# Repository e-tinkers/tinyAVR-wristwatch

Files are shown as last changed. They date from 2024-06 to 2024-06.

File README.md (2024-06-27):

## tinyAVR Wrist Watch

This is a derivated design from my entry for [Hackaday 2024 Business Card Challenge Contest](https://hackaday.io/project/196294-business-card-clock-attiny3227-dev-board). 

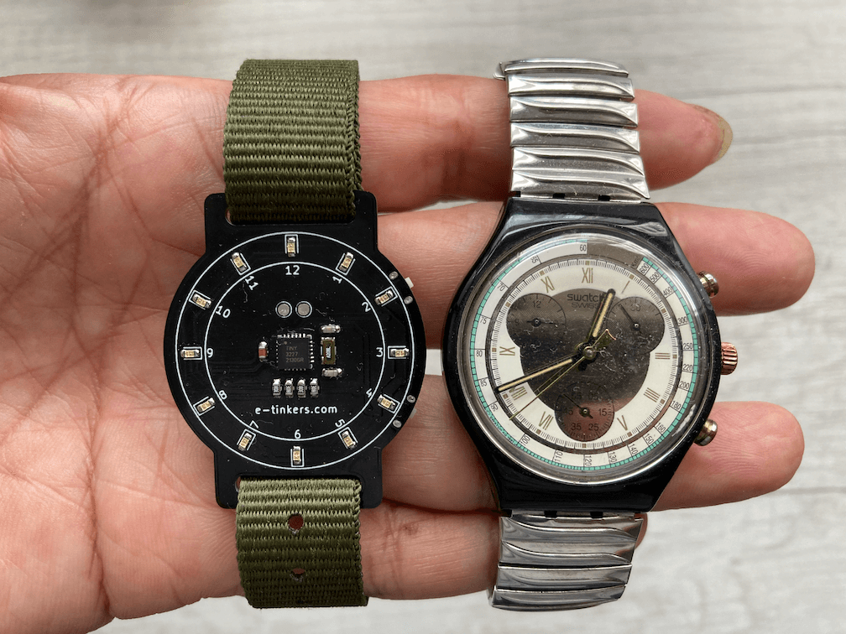
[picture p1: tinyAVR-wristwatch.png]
tinyAVR-wristwatch-with-belt


It shares the same [firmware](https://github.com/e-tinkers/tinyAVR_business_card_firmware) used in the [business card project](https://github.com/e-tinkers/tinyAVR-Business-Card), it has the same BOM with the exception of the two buttons used and without the two 12-pin break-out connector. I found a 16mm-wide wrist belt from Aliexpress and bought a few of them with different colors.

The wrist watch is powered by a CR2016 coin cell battery (96mAh) and has a sleep power consumption of less than 2uA, the battery life would be more than 3 years based on viewing the time 24 times/day.

Thanks [PCBWay](https://www.pcbway.com) for sponsoring the PCB fabrication.

You can ordering your PCB from [PCBWay](https://www.pcbway.com/project/shareproject/W515726AS2D5_gerber_22fd22c4.html)

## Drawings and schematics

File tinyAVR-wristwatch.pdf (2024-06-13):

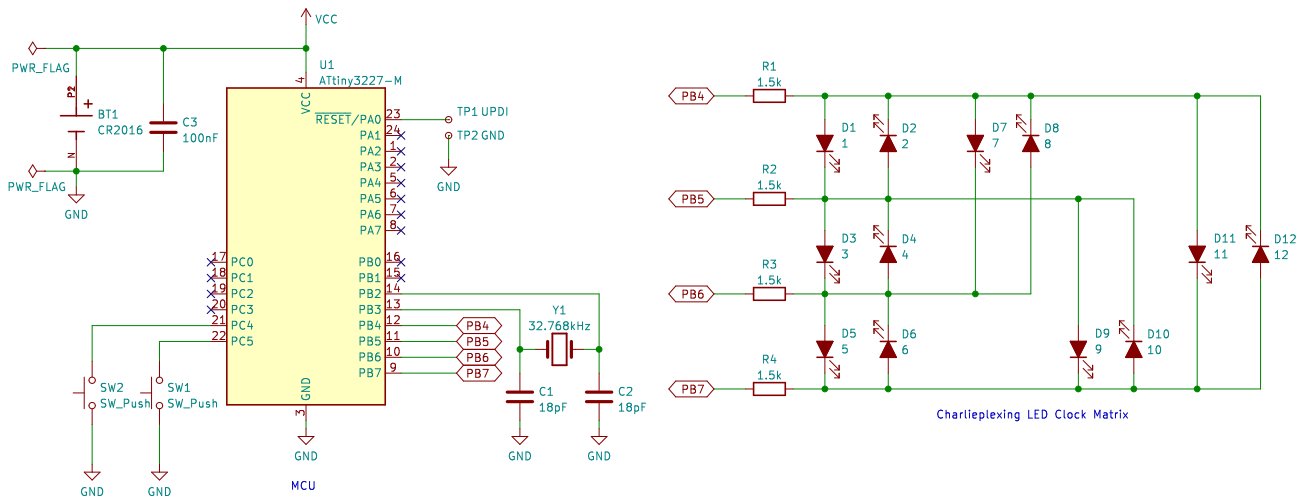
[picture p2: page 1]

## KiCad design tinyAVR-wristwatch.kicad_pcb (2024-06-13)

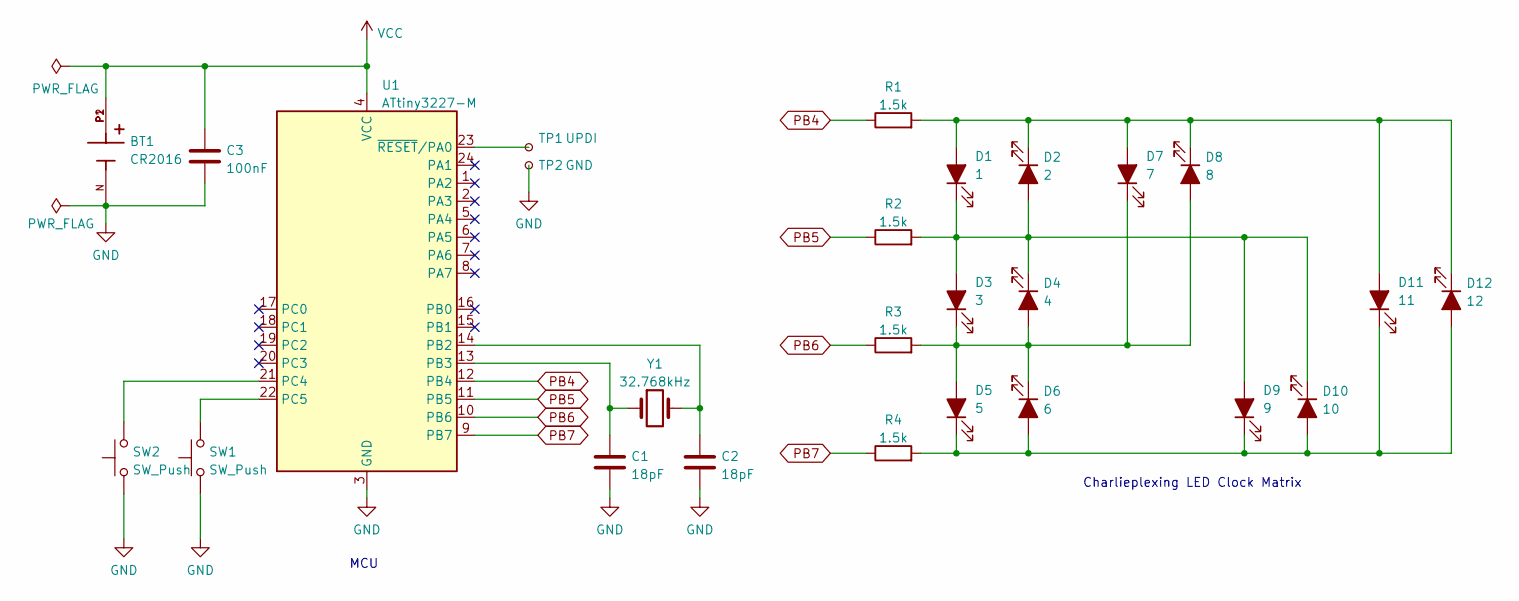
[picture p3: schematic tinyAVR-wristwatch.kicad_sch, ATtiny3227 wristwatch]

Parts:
BT1: CR2016; BatteryHolder_CR2016_SMD
C1, C2: 18pF; C_0603_1608Metric
C3: 100nF; C_0603_1608Metric
D1: 1; LED_0603_1608Metric
D2: 2; LED_0603_1608Metric
D3: 3; LED_0603_1608Metric
D4: 4; LED_0603_1608Metric
D5: 5; LED_0603_1608Metric
D6: 6; LED_0603_1608Metric
D7: 7; LED_0603_1608Metric
D8: 8; LED_0603_1608Metric
D9: 9; LED_0603_1608Metric
D10: 10; LED_0603_1608Metric
D11: 11; LED_0603_1608Metric
D12: 12; LED_0603_1608Metric
R1, R2, R3, R4: 1.5k; R_0603_1608Metric
SW1, SW2: SW_Push; KEY-SMD_TS3819ZJ
TP1: UPDI; TestPoint_Pad_D1.5mm
TP2: GND; TestPoint_Pad_D1.5mm
U1: ATtiny3227-M; QFN-24-1EP_4x4mm_P0.5mm_EP2.6x2.6mm
Y1: 32.768kHz; Crystal_SMD_3215-2Pin_3.2x1.5mm

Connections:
GND: BT1.N, C1.2, C2.2, C3.2, SW1.1, SW2.1, TP2.1, U1.3 (GND), U1.25 (GND)
unnamed: C1.1, U1.13 (PB3), Y1.1
unnamed: C2.1, U1.14 (PB2), Y1.2
unnamed: D1.1 (K), D2.2 (A), D3.2 (A), D4.1 (K), D9.2 (A), D10.1 (K), R2.2
unnamed: D1.2 (A), D2.1 (K), D7.2 (A), D8.1 (K), D11.2 (A), D12.1 (K), R1.2
unnamed: D3.1 (K), D4.2 (A), D5.2 (A), D6.1 (K), D7.1 (K), D8.2 (A), R3.2
unnamed: D5.1 (K), D6.2 (A), D9.1 (K), D10.2 (A), D11.1 (K), D12.2 (A), R4.2
unnamed: SW1.2, U1.22 (PC5)
unnamed: SW2.2, U1.21 (PC4)
unnamed: TP1.1, U1.23 (~RESET/PA0)
PB4: R1.1, U1.12 (PB4)
PB5: R2.1, U1.11 (PB5)
PB6: R3.1, U1.10 (PB6)
PB7: R4.1, U1.9 (PB7)
VCC: BT1.P1, BT1.P2, C3.1, U1.4 (VCC)

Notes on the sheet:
MCU
Charlieplexing LED Clock Matrix

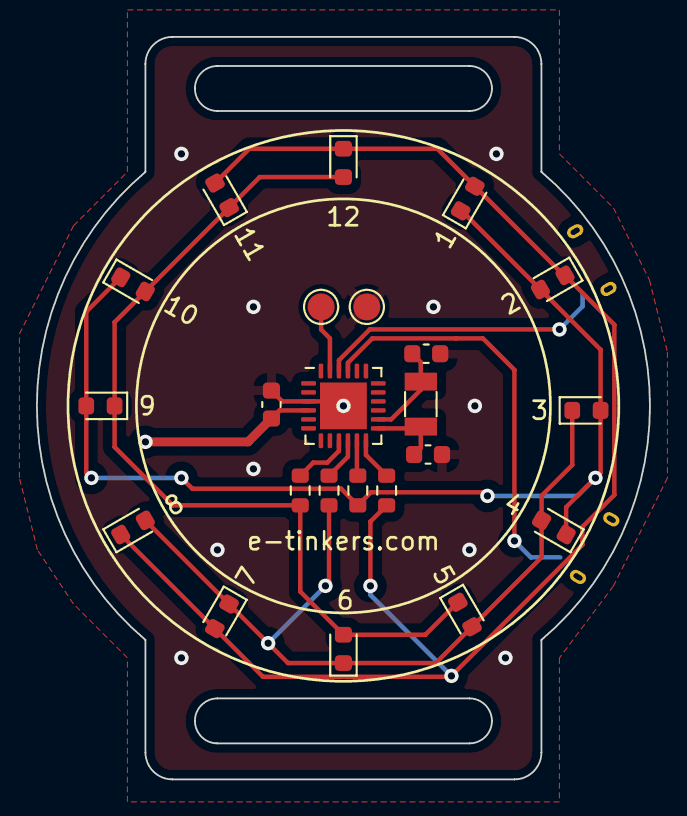
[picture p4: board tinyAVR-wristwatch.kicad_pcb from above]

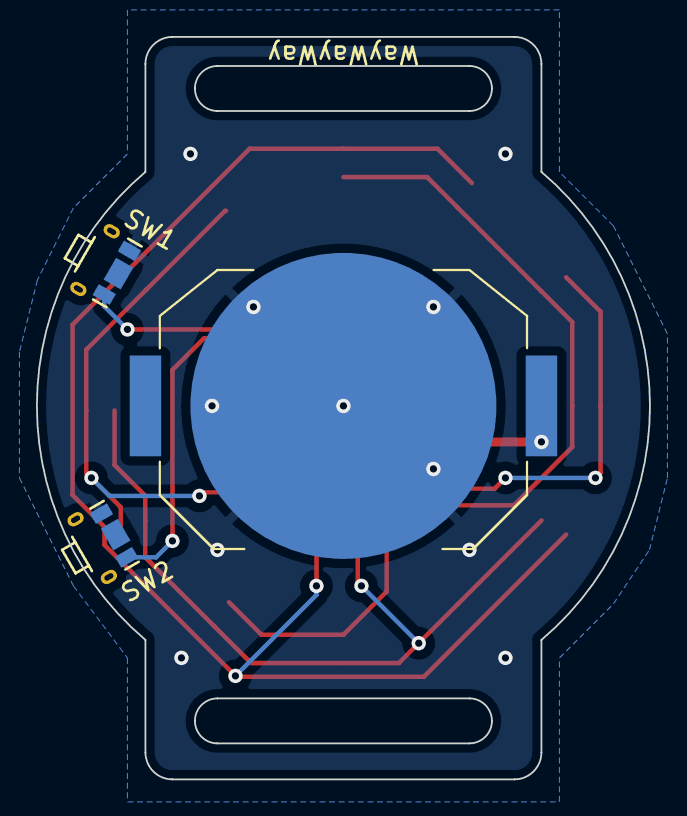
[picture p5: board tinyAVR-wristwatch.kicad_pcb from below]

Board: 2 copper layers, 34.1 x 41.2 mm, 26 parts (3 on the bottom side), 15 nets.

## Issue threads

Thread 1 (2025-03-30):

Error in PCB layout

ku4qo, 2025-03-30:
Switch SW2 has a missing ground connection on the back copper layer. SW2 won't work without it. Soldering a small jumper from the pin to the back ground plane fixes the issue.

e-tinkers, 2025-03-31:
BTW, the part that I used for SW2 is [C6386917](https://www.lcsc.com/datasheet/lcsc_datasheet_2305231109_SHOU-HAN-TS3819ZJ-160gf_C6386917.pdf) ordered from LCSC.com, if you are using a different part, the connection might be different.

Closed 2025-03-31.

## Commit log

2024-06-13 remove gerber files
    [tinyAVR-wristwatch-B_Cu.gbr, tinyAVR-wristwatch-B_Mask.gbr, tinyAVR-wristwatch-B_Paste.gbr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]
2024-06-27 add PCB ordering link
